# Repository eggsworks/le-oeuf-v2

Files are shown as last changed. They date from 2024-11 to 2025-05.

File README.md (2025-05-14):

## L'oeuf

An ultra-low profile (Kailh PG1316S) keyboard inspired by Le Chiffre.

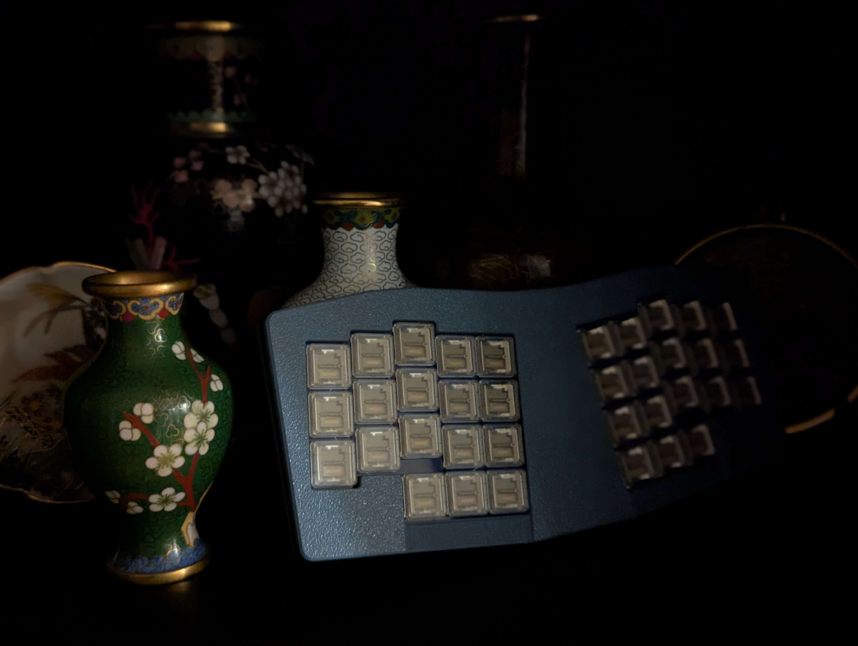
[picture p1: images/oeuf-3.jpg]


## PCB

L'oeuf is a semi-integrated PCB using an E73 BLE module. It is intended to be fully SMT assembled.

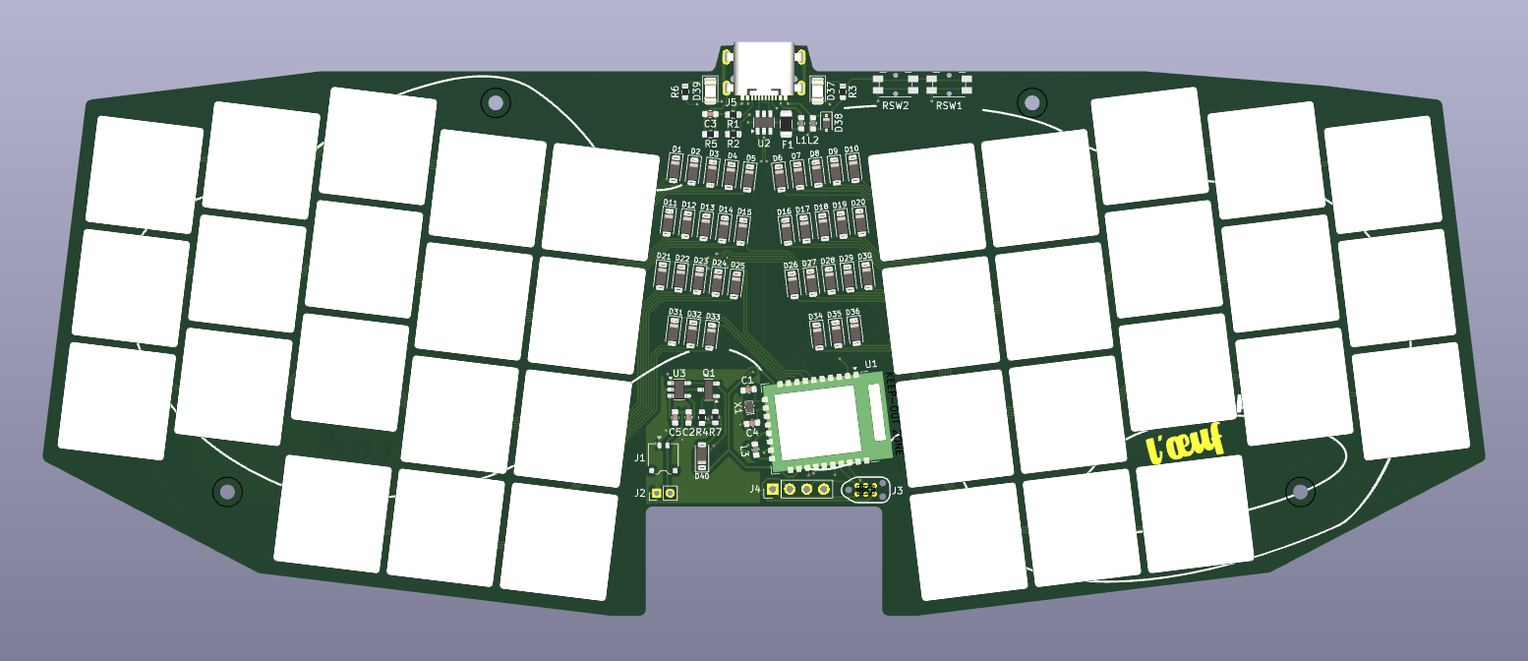
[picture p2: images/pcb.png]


A mid-mount USB-C port and JST ACH battery connector keep the board as thin as possible.

## Firmware

ZMK firmware available from [eggsworks/zmk-config](https://github.com/eggsworks/zmk-config/)

## License

This design is available under the terms of the [CERN-OHL-S](LICENSE).

## Acknowledgements

- Inspired by the original [tominabox1/Le-Chiffre-Keyboard](https://github.com/tominabox1/Le-Chiffre-Keyboard/)
- E73 supporting circuitry derived from [krikun98/Willis](https://github.com/krikun98/Willis)
- MCU footprint derived from [ebastler/marbastlib](https://github.com/ebastler/marbastlib/)
- Switch footprint derived from [mikeholscher/zmk-config-mikefive](https://github.com/mikeholscher/zmk-config-mikefive/)
- Layout derived from ergogen source supplied for [sporkus/le_capybara_keyboard](https://github.com/sporkus/le_capybara_keyboard)
- PCB art kindly provided by transthropology

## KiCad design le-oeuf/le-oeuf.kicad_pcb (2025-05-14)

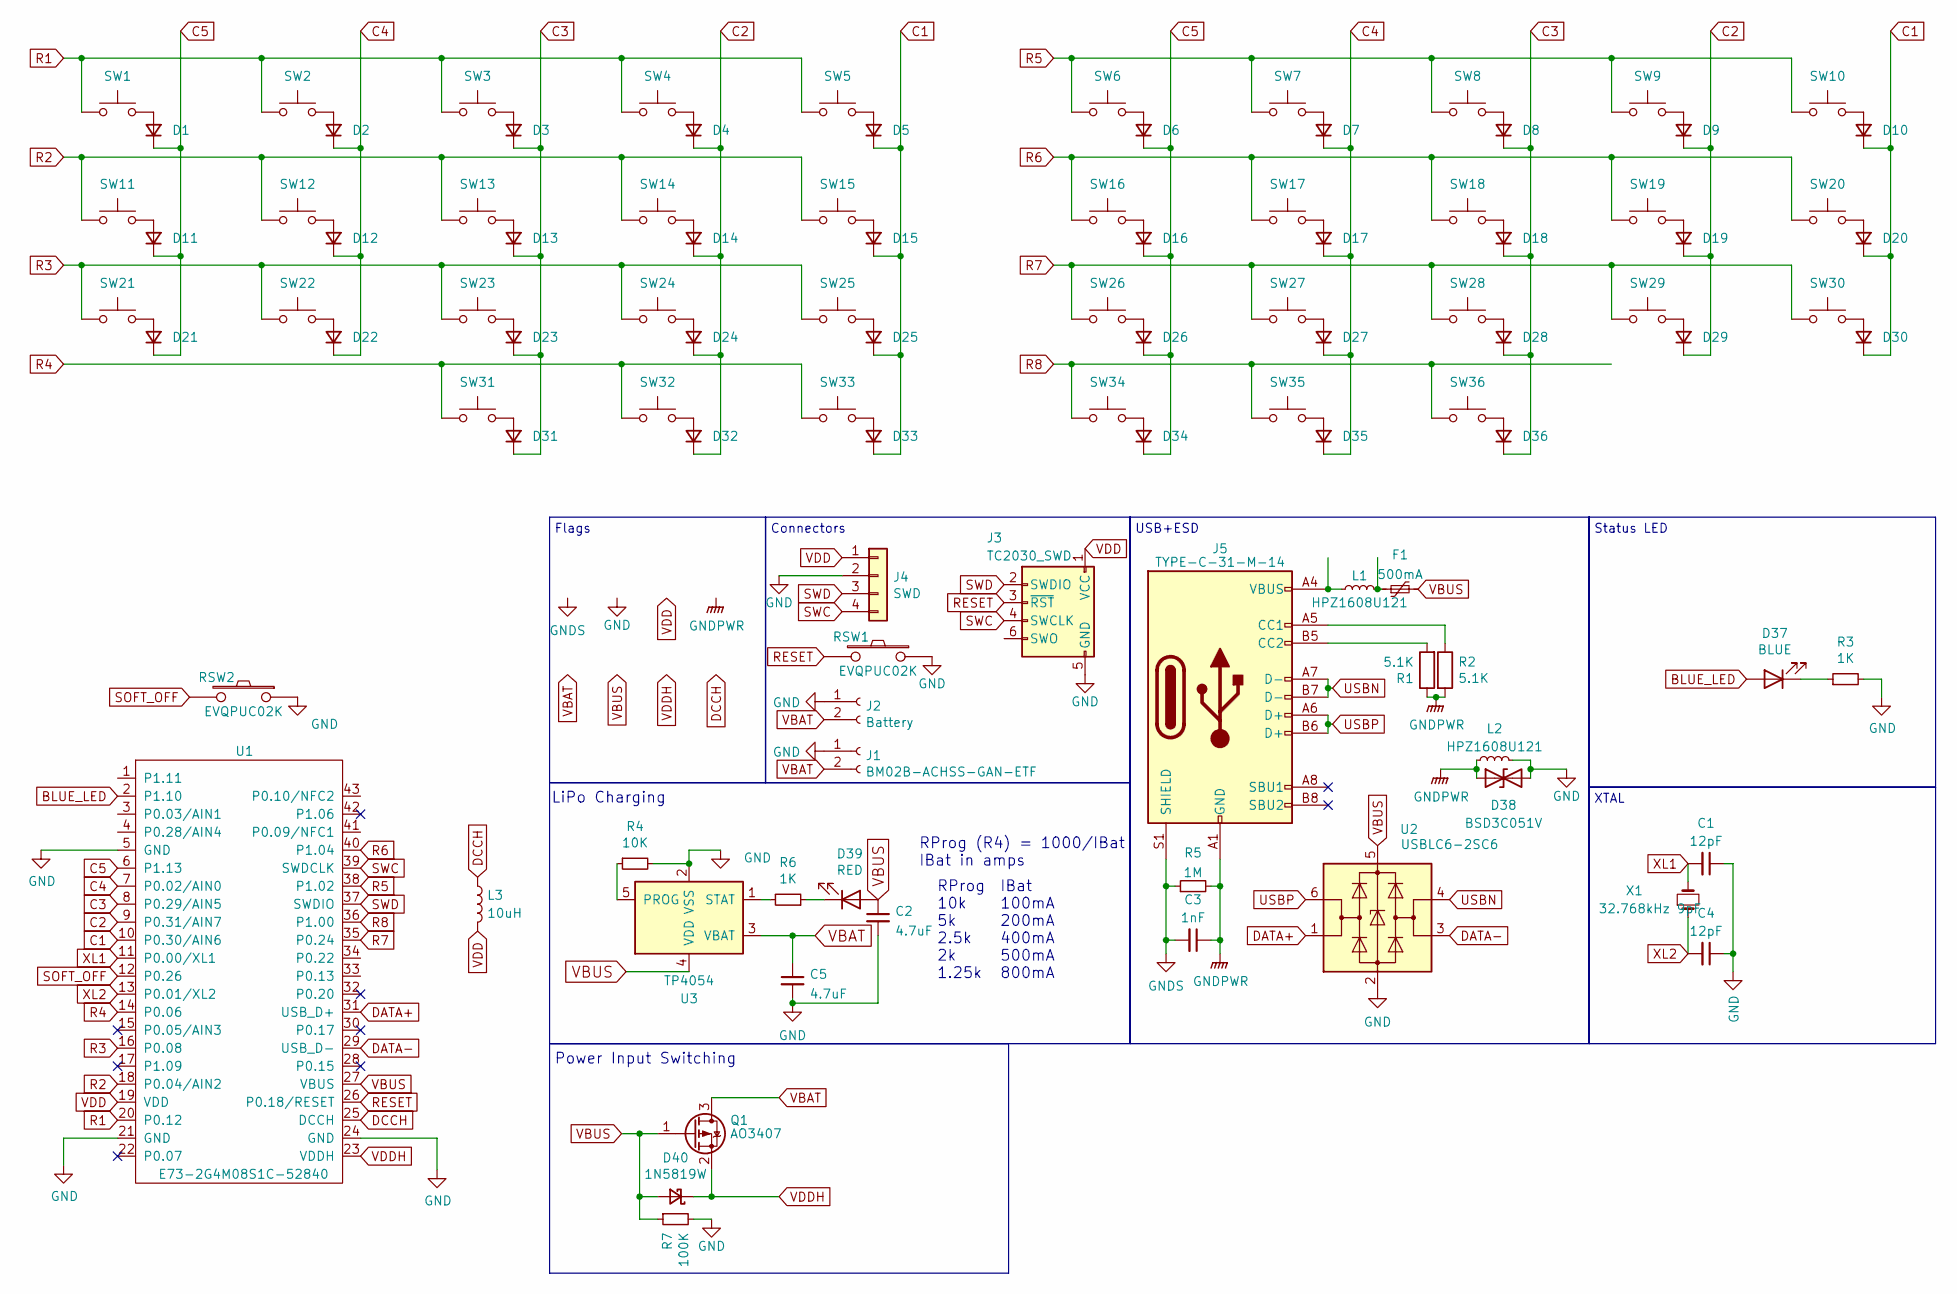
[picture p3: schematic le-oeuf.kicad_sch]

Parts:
C1, C4: 12pF; C_0603_1608Metric; MPN 0603CG120J500NT; LCSC C1642
C2, C5: 4.7uF; C_0603_1608Metric; MPN CL10A475KO8NNNC; LCSC C19666
C3: 1nF; C_0603_1608Metric; MPN CL10B102KB8NNNC; LCSC C1588
D1, D2, D3, D4, D5, D6, D7, D8, D9, D10, D11, D12, D13, D14, D15, D16, D17, D18, D19, D20, D21, D22, D23, D24, D25, D26, D27, D28, D29, D30, D31, D32, D33, D34, D35, D36, D40: 1N5819W; D_SOD-123; MPN 1N5819W; LCSC C727115
D37: BLUE; LED_1206_3216Metric; MPN XL-3216UBC; LCSC C965827
D38: BSD3C051V; D_SOD-323; MPN BSD3C051V; LCSC C151996
D39: RED; LED_1206_3216Metric; MPN XL-3216SURC; LCSC C965822
F1: 500mA; Fuse_1206_3216Metric; MPN BSMD1206-050-6V; LCSC C883122
J1: BM02B-ACHSS-GAN-ETF; JST_ACH_BM02B-ACHSS-GAN-ETF_1x02-1MP_P1.20mm_Vertical; MPN BM02B-ACHSS-GAN-ETF(LF)(SN); LCSC C5118738
J2: Battery; PinHeader_1x02_P2.00mm_Vertical
J3: TC2030_SWD; CON_TC2030_outlined
J4: SWD; PinHeader_1x04_P2.54mm_Vertical
J5: TYPE-C-31-M-14; USB_C_Receptacle_HRO_TYPE-C-31-M-14; MPN TYPE-C-31-M-14; LCSC C223907
L1, L2: HPZ1608U121; L_0603_1608Metric; MPN HPZ1608U121-2R0TF; LCSC C919153
L3: 10uH; L_0603_1608Metric; MPN MLF1608E100JT000; LCSC C275361
Q1: AO3407; SOT-23; MPN AO3407; LCSC C5148473
R1, R2: 5.1K; R_0603_1608Metric; MPN RC0603FR-075K1L; LCSC C105580
R3, R6: 1K; R_0603_1608Metric; MPN RC0603FR-071KL; LCSC C22548
R4: 10K; R_0603_1608Metric; MPN 0603WAF1002T5E; LCSC C25804
R5: 1M; R_0603_1608Metric; MPN 0603WAF1004T5E; LCSC C22935
R7: 100K; R_0603_1608Metric; MPN RC0603FR-07100KL; LCSC C14675
RSW1, RSW2: EVQPUC02K; Panasonic_EVQPUL_EVQPUC; MPN EVQPUC02K; LCSC C79174
SW1, SW2, SW3, SW4, SW5, SW6, SW7, SW8, SW9, SW10, SW11, SW12, SW13, SW14, SW15, SW16, SW17, SW18, SW19, SW20, SW21, SW22, SW23, SW24, SW25, SW26, SW27, SW28, SW29, SW30, SW31, SW32, SW33, SW34, SW35, SW36: PG1425; CPG1316S01D02_mikeholscher
U1: E73-2G4M08S1C-52840; nRF52840_E73-2G4M08S1C; MPN C356849; LCSC C356849
U2: USBLC6-2SC6; TSOT-23-6; MPN TPUSBLC6-2SC6; LCSC C558442
U3: TP4054; SOT-23-5; MPN TP4054; LCSC C5381776
X1: 32.768kHz 9pF; Crystal_SMD_MicroCrystal_CM9V-T1A-2Pin_1.6x1.0mm; MPN X161032768KLD2SI; LCSC C383846

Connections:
BLUE_LED: D37.2 (A), U1.2 (P1.10)
C1: D5.1 (K), D10.1 (K), D15.1 (K), D20.1 (K), D25.1 (K), D30.1 (K), D33.1 (K), U1.10 (P0.30/AIN6)
C2: D4.1 (K), D9.1 (K), D14.1 (K), D19.1 (K), D24.1 (K), D29.1 (K), D32.1 (K), U1.9 (P0.31/AIN7)
C3: D3.1 (K), D8.1 (K), D13.1 (K), D18.1 (K), D23.1 (K), D28.1 (K), D31.1 (K), D36.1 (K), U1.8 (P0.29/AIN5)
C4: D2.1 (K), D7.1 (K), D12.1 (K), D17.1 (K), D22.1 (K), D27.1 (K), D35.1 (K), U1.7 (P0.02/AIN0)
C5: D1.1 (K), D6.1 (K), D11.1 (K), D16.1 (K), D21.1 (K), D26.1 (K), D34.1 (K), U1.6 (P1.13)
DATA+: U1.31 (USB_D+), U2.1 (I/O1)
DATA-: U1.29 (USB_D-), U2.3 (I/O2)
DCCH: L3.1, U1.25 (DCCH)
GND: C1.1, C2.2, C4.1, C5.2, D38.2 (A2), J1.1, J2.1, J3.5 (GND), J4.2, L2.2, R3.2, R4.2, R7.2, RSW1.1, RSW2.1, U1.5 (GND), U1.21 (GND), U1.24 (GND), U2.2 (GND), U3.2 (VSS)
GNDPWR: C3.1, D38.1 (A1), J5.A1 (GND), J5.A12 (GND), J5.B1 (GND), J5.B12 (GND), L2.1, R1.1, R2.2, R5.2
GNDS: C3.2, J5.S1 (SHIELD), R5.1
unnamed: D1.2 (A), SW1.2
unnamed: D2.2 (A), SW2.2
unnamed: D3.2 (A), SW3.2
unnamed: D4.2 (A), SW4.2
unnamed: D5.2 (A), SW5.2
unnamed: D6.2 (A), SW6.2
unnamed: D7.2 (A), SW7.2
unnamed: D8.2 (A), SW8.2
unnamed: D9.2 (A), SW9.2
unnamed: D10.2 (A), SW10.2
unnamed: D11.2 (A), SW11.2
unnamed: D12.2 (A), SW12.2
unnamed: D13.2 (A), SW13.2
unnamed: D14.2 (A), SW14.2
unnamed: D15.2 (A), SW15.2
unnamed: D16.2 (A), SW16.2
unnamed: D17.2 (A), SW17.2
unnamed: D18.2 (A), SW18.2
unnamed: D19.2 (A), SW19.2
unnamed: D20.2 (A), SW20.2
unnamed: D21.2 (A), SW21.2
unnamed: D22.2 (A), SW22.2
unnamed: D23.2 (A), SW23.2
unnamed: D24.2 (A), SW24.2
unnamed: D25.2 (A), SW25.2
unnamed: D26.2 (A), SW26.2
unnamed: D27.2 (A), SW27.2
unnamed: D28.2 (A), SW28.2
unnamed: D29.2 (A), SW29.2
unnamed: D30.2 (A), SW30.2
unnamed: D31.2 (A), SW31.2
unnamed: D32.2 (A), SW32.2
unnamed: D33.2 (A), SW33.2
unnamed 45: D34.2 (A), SW34.2; also elsewhere on the board
unnamed: D35.2 (A), SW35.2
unnamed: D36.2 (A), SW36.2
unnamed: D37.1 (K), R3.1
unnamed: D39.1 (K), R6.1
unnamed: F1.1, L1.2
unnamed: J5.A5 (CC1), R2.1
unnamed: J5.B5 (CC2), R1.2
unnamed: J5.A4 (VBUS), J5.A9 (VBUS), J5.B4 (VBUS), J5.B9 (VBUS), L1.1
unnamed: R4.1, U3.5 (PROG)
unnamed: R6.2, U3.1 (STAT)
R1: SW1.1, SW2.1, SW3.1, SW4.1, SW5.1, U1.20 (P0.12)
R2: SW11.1, SW12.1, SW13.1, SW14.1, SW15.1, U1.18 (P0.04/AIN2)
R3: SW21.1, SW22.1, SW23.1, SW24.1, SW25.1, U1.16 (P0.08)
R4: SW31.1, SW32.1, SW33.1, U1.14 (P0.06)
R5: SW6.1, SW7.1, SW8.1, SW9.1, SW10.1, U1.38 (P1.02)
R6: SW16.1, SW17.1, SW18.1, SW19.1, SW20.1, U1.40 (P1.04)
R7: SW26.1, SW27.1, SW28.1, SW29.1, SW30.1, U1.35 (P0.24)
R8: SW34.1, SW35.1, SW36.1, U1.36 (P1.00); also elsewhere on the board
RESET: J3.3 (~RST), RSW1.2, U1.26 (P0.18/RESET)
SOFT_OFF: RSW2.2, U1.12 (P0.26)
SWC: J3.4 (SWCLK), J4.4, U1.39 (SWDCLK)
SWD: J3.2 (SWDIO), J4.3, U1.37 (SWDIO)
USBN: J5.A7 (D-), J5.B7 (D-), U2.4 (I/O2)
USBP: J5.A6 (D+), J5.B6 (D+), U2.6 (I/O1)
VBAT: C5.1, J1.2, J2.2, Q1.3 (D), U3.3 (VBAT)
VBUS: C2.1, D39.2 (A), D40.2 (A), F1.2, Q1.1 (G), R7.1, U1.27 (VBUS), U2.5 (VBUS), U3.4 (VDD)
VDD: J3.1 (VCC), J4.1, L3.2, U1.19 (VDD)
VDDH: D40.1 (K), Q1.2 (S), U1.23 (VDDH)
XL1: C1.2, U1.11 (P0.00/XL1), X1.2
XL2: C4.2, U1.13 (P0.01/XL2), X1.1

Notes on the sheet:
RProg 10k 5k 2.5k 2k 1.25k
Connectors
LiPo Charging
Power Input Switching
XTAL
IBat 100mA 200mA 400mA 500mA 800mA
Flags
Status LED
USB+ESD
RProg (R4) = 1000/IBat IBat in amps

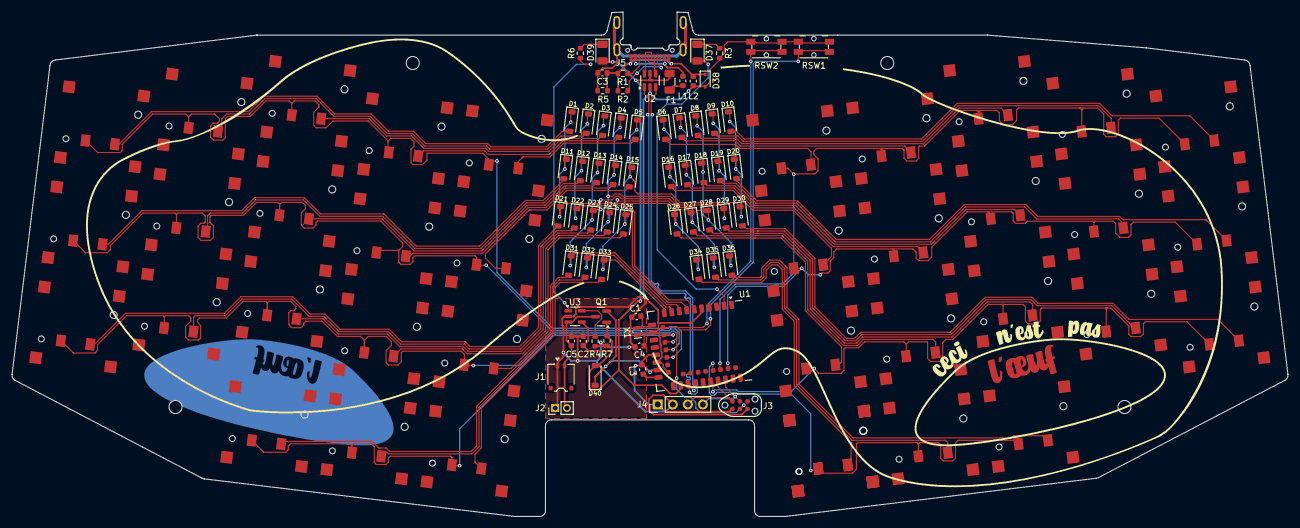
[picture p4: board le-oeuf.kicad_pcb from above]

Board: 2 copper layers, 215.1 x 85.0 mm, 105 parts (0 on the bottom side), 76 nets.

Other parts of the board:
SW34#2: PG1425; CPG1316S01D02_mikeholscher

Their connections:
unnamed 45: SW34#2.2; also elsewhere on the board
R8: SW34#2.1; also elsewhere on the board

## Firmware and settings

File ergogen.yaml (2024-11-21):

meta:
  engine: 4.0.0
  name: le_oeuf
  version: 0.1
  author: tmick0
  url: https://github.com/eggsworks/

presets:
  x_spaced:
    capx: 16.85
    capy: capx
    kx: 17
    ky: kx
    edge_cut_padding: 1
    split_angle: 7

    # distance from inner top key to knob/center switch
    centerx: 24.347
    centery: 5.202

    originx: 120
    originy: -100

units:
  $extends: presets.x_spaced
  edgex: capx/2 + edge_cut_padding  #distance from middle of the switch to pcb edge
  edgey: capy/2 + edge_cut_padding


points:
  # Keys/Switches
  # =============
  zones.matrix:
    mirror: &mirror
      ref: matrix_inner_top
      shift: [0, 0]
      distance: 24.347 * 2
    anchor.shift: [originx, originy]
    rotate: -split_angle
    key:
      width: capx
      height: capy
      spread: kx
      padding: ky
      bind: [edgex, edgey]
    rows:
      bottom:
      home:
      top:
    columns:
      pinky:
      ring.key:
        stagger: 1/4ky
      middle.key:
        stagger: 0.25ky
      index.key:
        stagger: -0.25ky
      inner:

  zones.3thumbs:
    mirror: *mirror
    key:
      $extends: points.zones.matrix.key
      width: 1 * capx
    anchor:
      - ref: matrix_ring_bottom
        shift: [kx, -ky]
    columns:
      3rd:
      2nd:
      main:
        key:
          width: 1 * capx

outlines:
  _switch_pos:
    - what: circle
      where:
        - /matrix_.*/
        - /.*thumb.*/
        - /knob/
      radius: 1
      bound: false
  _switch_comment:
    - what: rectangle
      operation: stack
      where:
        - /matrix_.*/
        - /.thumb.*/
        - /knob/
      size: [kx, ky]
      bound: false
  _keycaps:
    - what: rectangle
      where:
        - /matrix_.*/
        - /.*thumb.*/
      size: [capx, capy]
      bound: false
  
  kicad_ref:
    - ^_switch_pos
    - ^_switch_comment

  kicad_center:
    - ^_switch_pos

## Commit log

2024-11-21 prepare for publication
    [le-oeuf.kicad_pcb]
2024-11-23 Add case and update readme
    [oeuf-poche.stl]
2024-11-26 do not push this commit
    [le-oeuf.kicad_pcb, le-oeuf.kicad_sch]
2024-12-01 finish routing
    [le-oeuf.kicad_pcb, le-oeuf.kicad_sch]
2024-12-12 import art
    [le-oeuf.kicad_pcb, le-oeuf.kicad_sch]
2024-12-18 prototype ordered
    [le-oeuf.kicad_pcb, le-oeuf.kicad_sch]
2024-12-20 bom updates
    [le-oeuf.kicad_pcb, le-oeuf.kicad_sch]
2025-05-14 Cleanup for v2 push
    [le-oeuf.kicad_pcb, le-oeuf.kicad_sch, oeuf-poche.stl]
2025-05-14 Add switch footprint
2025-05-14 Remove PG1425 footprint
2025-05-14 Remove xiao footprint

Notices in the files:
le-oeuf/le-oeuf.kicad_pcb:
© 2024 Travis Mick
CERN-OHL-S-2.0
